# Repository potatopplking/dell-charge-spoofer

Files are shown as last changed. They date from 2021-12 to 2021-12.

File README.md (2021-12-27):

# Yet another Dell charge spoofer

Spoofer emulates genuine Dell laptop charger, allowing you to charge your laptop with any power source (with correct voltage and current rating). Built using ATTiny13. This spoofer is very simple, containing only 2 ICs and a few resistors and capacitors.

## Motivation

If you need to use your Dell laptop with non-original charger (or any generic power source), you need to emulate communication between laptop and charger. This communication takes place on 1-wire bus (center pin of laptop power in connector).

## Usage

### Prerequisities

On the software side, you'll need `avr-gcc`, `avr-libc` and `avrdude`. For the hardware you'll need some AVR programmer and a spoofer (it's easy to build one yourself!).

### Compile & flash

```
make compile
make fuse # set AVR fuses (config bits)
make flash
```

### Connect

See schematic. Connect GND and output voltage of your source to voltage input of spoofer. Connect center pin of the laptop connector to DATA pin of spoofer. GND should go on the outer shield of connector, voltage should be connected to inner shield of connector.

*Important: spoofer doesn't regulate or monitor voltage of the power source - it's up to you to check that voltage matches original charger!*

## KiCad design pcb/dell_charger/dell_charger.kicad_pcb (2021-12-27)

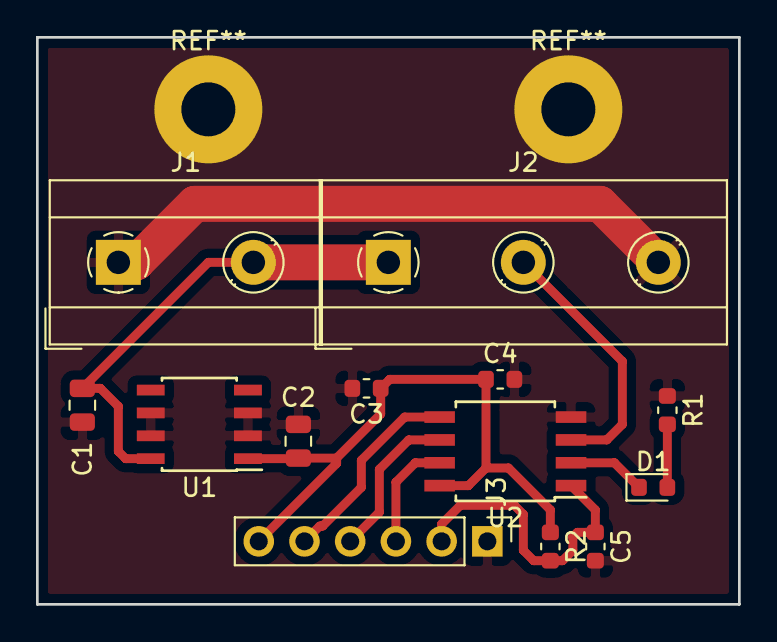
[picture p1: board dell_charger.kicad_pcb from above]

Board: 2 copper layers, 39.0 x 31.5 mm, 13 parts (0 on the bottom side), 10 nets.

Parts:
C1, C2: 10u; C_0805_2012Metric
C3: 1u; C_0603_1608Metric
C4, C5: 100n; C_0603_1608Metric
D1: LED; LED_0603_1608Metric
J1: Input terminal; TerminalBlock_MetzConnect_Type171_RT13702HBWC_1x02_P7.50mm_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
J2: Output terminal; TerminalBlock_MetzConnect_Type171_RT13703HBWC_1x03_P7.50mm_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
J3: Programmer; PinHeader_1x06_P2.54mm_Vertical
R1: 470; R_0603_1608Metric
R2: 4k7; R_0603_1608Metric
U1: L78L05_SO8; SOIC-8_3.9x4.9mm_P1.27mm
U2: ATtiny13-20SU; SOIJ-8_5.3x5.3mm_P1.27mm

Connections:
+5V: C2.1, C3.1, C4.1, J3.6, R2.1, U1.1, U2.8
/DATA: J2.2, U2.3
/LED: D1.1, U2.2
/MISO: J3.4, U2.6
/MOSI: J3.5, U2.5
/SCK: J3.3, U2.7
GND: C1.2, C2.2, C3.2, C4.2, C5.2, J1.1, J2.3, J3.1, R1.1, U1.2, U1.3, U1.6, U1.7, U2.4
unnamed: C1.1, J1.2, J2.1, U1.8
unnamed: C5.1, J3.2, R2.2, U2.1
unnamed: D1.2, R1.2

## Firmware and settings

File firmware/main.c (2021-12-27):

/*
 * Dell laptop power adapter spoofer for ATTiny13
 * MCU has to run on 9.6 MHz (don't forget to set fuses!)
 * Probably would run on other AVR of the same specs and frequency,
 * though timing is critical
 * 
 * Hardware connections:
 * - connect VCC from powersource directly to laptop VCC adapter input
 * - connect GND from powersource directly to laptop GND adapter input
 * - connect data wire of laptop adapter input to PB4 of ATTINY13
 * - [optional] PB3 to LED, which indicates that laptop is connected
 * Devices (laptop, ATTINY13) must share common ground!
 */ 

#define F_CPU 9600000UL /* 9.6 MHz - don't forget to set fuses! (check Makefile) */
#include <avr/io.h>
#include <util/delay.h>
#include <avr/wdt.h>

/*
 * Definitions
 */

#define ONEWIRE_PIN_DDR DDB4
#define ONEWIRE_PIN_PORT PB4
#define ONEWIRE_PIN_IN PINB4
#define LED_PIN_DDR DDB3
#define LED_PIN_PORT PB3

/*
 * Macros
 */

/* check whether bus is low or high */
#define BUS_HIGH (PINB & (1 << ONEWIRE_PIN_IN))
#define BUS_LOW !BUS_HIGH

/* 1-Wire is open-drain bus with pull-up resistors to 3 - 5 V */
/* set bus to logical low - PORTB for given pin must be zero */
#define SET_BUS_LOW DDRB |= (1 << ONEWIRE_PIN_DDR)
/* release bus - PORTB for given pin must be zero */
#define RELEASE_BUS DDRB &= ~(1 << ONEWIRE_PIN_DDR)

/* LED */
#define INIT_LED DDRB |= (1 << LED_PIN_DDR)
#define SET_LED_OFF PORTB |= (1 << LED_PIN_PORT)
#define SET_LED_ON PORTB &= ~(1 << LED_PIN_PORT)

/*
 * Watchdog functions
 */

void WDT_init(void)
{
    wdt_reset();
    /* disable interrupts - probably default settings */
    WDTCR &= ~(1<<WDTIE);
    /* Start timed sequence & enable (necessary to modify prescaler) */
    WDTCR |= (1<<WDCE) | (1<<WDE);
    /* Set new prescaler(time-out) value = 64K cycles (~0.5 s) */
    WDTCR = (1<<WDE) | (1<<WDP2) | (1<<WDP0);
}

void WDT_off(void)
{
    wdt_reset();
    /* Clear WDRF in MCUSR */
    MCUSR &= ~(1<<WDRF);
    /* Write logical one to WDCE and WDE */
    /* Keep old prescaler setting to prevent unintentional time-out 
    */
    WDTCR |= (1<<WDCE) | (1<<WDE);
    /* Turn off WDT */
    WDTCR = 0x00;
}


/*
 * 1-Wire functions
 */

uint8_t onewire_read_byte()
{
    /* note: data are sent LSB first */
    uint8_t data = 0;
    uint8_t i;
    _delay_us(1); /* wait 1 us - critical, do not remove */
    for (i = 0; i < 8; i++) {
        /* wait for falling edge */
        while (BUS_HIGH) {
            /* do nothing */
        }
        /* wait 30 us */
        _delay_us(30);
        /* sample bit */
        data <<= 1;
        if (BUS_HIGH) {
            data |= 0x01;
        }
        /* wait until bus goes back up */
        while (BUS_LOW);
    }
    return data;
}

void onewire_write_byte(const uint8_t data)
{
    /* note: data are sent LSB first */
    uint8_t mask = 0x01;
    uint8_t i;
    for (i = 0; i < 8; i++) {
        /* wait for falling edge */
        while (BUS_HIGH) {
            /* do nothing */
        }
        /* master releases bus after 7.625 us; set bit */
        if (data & mask) {
            RELEASE_BUS;
        } else {
            SET_BUS_LOW;
        }
        mask <<= 1;
        /* master samples after 9 us; release bus after 30 us (55 us max time) */
        _delay_us(30);
        RELEASE_BUS;
        /* wait for rising edge */
        while (BUS_LOW) {
            /* do nothing */
        }
    }
    return;
}

/*
 * Main
 */

int main(void)
{
    const uint8_t delay = 50;
    /* slave response: last three bytes indicate power capability in Watts
     * (ASCII: '0', '6', '5' is 65 W; '0', '9', '0' is 90 W) */
    const uint8_t slave_response[] = {0x27, 0x41, 0x43, '0', '6', '5' };
    uint8_t buffer[8];
    uint8_t slave_response_len = sizeof(slave_response) / sizeof(slave_response[1]);
    uint8_t master_msg_len = 4;
    uint8_t i;
    uint16_t counter;

    DDRB = 0;
    PORTB = 0;
    RELEASE_BUS;
    INIT_LED;
    SET_LED_OFF;
    while (1) {
        /* Turn LED on if charger connected to laptop */
        //SET_LED_ON;
        /* disable watchdog timer */
        WDT_off();
        /* wait for falling edge */
        while (BUS_HIGH);
        /* enable watchdog timer */
        WDT_init();
        SET_LED_OFF;
        counter = 0;
        while (BUS_LOW) {
            _delay_us(delay);
            counter++;
        }
        /* Master initiates communication by pulling bus low for more than 480 us */
        if (counter > (480 / delay) && counter < (1000 / delay)) {
            /* 480 < t_low < 1000 [us], RESET: 
             * slave sends PRESENCE condition - keep bus low for 120 us 
             */
            _delay_us(10);
            SET_BUS_LOW;
            _delay_us(120);
            RELEASE_BUS;
            /* Receive 4 B from master:
             *   0xCC (SKIP ROM command)
             *   0xF0 (240, ?)
             *   0x06 (?)
             *   0x00 (?)
             * (LSB first when sending over 1-wire)
             */
            for (i = 0; i < master_msg_len; i++) {
                /* nothing is being checked here; just reading out some stuff to make master happy */
                buffer[i] = onewire_read_byte();
            }
            /* Slave response for two types of power adapter:
             *  +---------------+---------------+
             *  | 65W DELL      |   180W DELL   |
             *  +---------------+---------------+
             *  |  0x27 (?)     |    0x27 (?)   |
             *  |  0x41 ('A')   |    0x41 ('A') |
             *  |  0x43 ('C')   |    0x43 ('C') |
             *  |  0x30 ('0')   |    0x31 ('1') |
             *  |  0x36 ('6')   |    0x38 ('8') |
             *  |  0x35 ('5')   |    0x30 ('0') |
             *  +---------------+---------------+
             * Where last three bytes seem to indicate power output. Known options: 65 W, 90 W, 180 W
             */
            for (i = 0; i < slave_response_len; i++) {
                onewire_write_byte(slave_response[i]);
            }
            /* done! */
            SET_LED_ON;
        }
        /* reset watchdog */
        wdt_reset();
    }
    return 0;
}
